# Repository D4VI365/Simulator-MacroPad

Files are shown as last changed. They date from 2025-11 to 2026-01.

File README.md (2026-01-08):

# Simulator-MacroPad

My project for the macropad contest of hackclub. It has 12 buttons as well as 1 rotary encoder with two leds which indicate the level of the encoder using colours.

I plan on using this pad to help me with my in-race adjustments, as well using it in other applications by mapping the buttons to do specific actions (like muting discord or actions of voicemod) or attaching more complex macros to them

BottomBox:

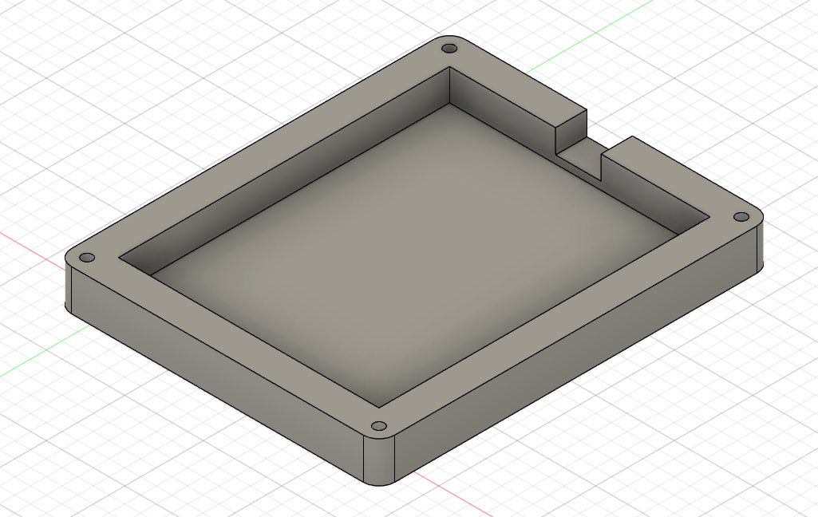
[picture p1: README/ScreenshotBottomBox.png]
BottomBox


TopCover:
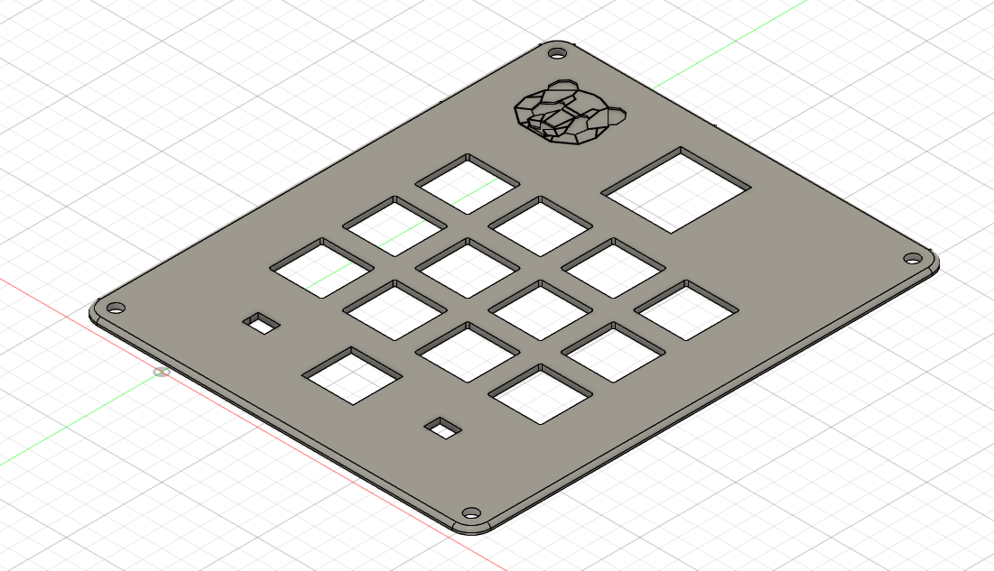
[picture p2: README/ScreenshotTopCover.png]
TopCover


FullBox:
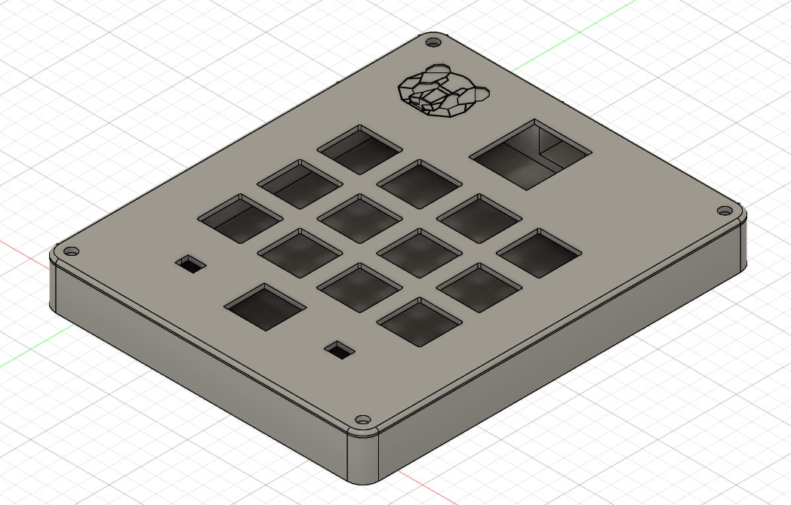
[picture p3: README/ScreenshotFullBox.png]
FullBox


BottomBox+PCB:
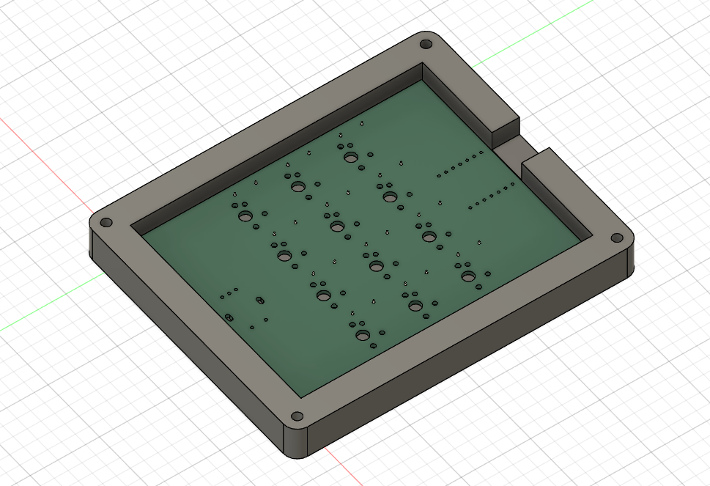
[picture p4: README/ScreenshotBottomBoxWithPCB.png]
BottomBoxWithPCB


Full Assemble:
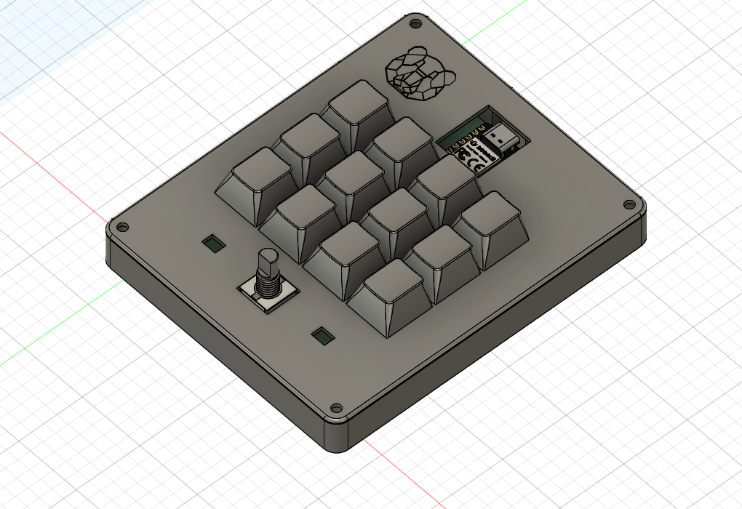
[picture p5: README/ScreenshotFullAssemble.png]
FullAssemble


PCB:
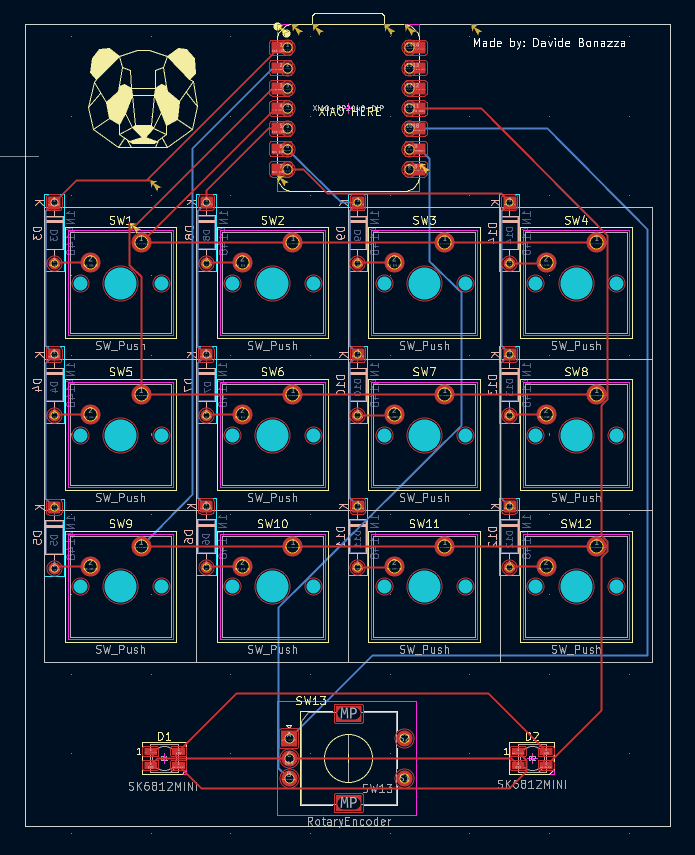
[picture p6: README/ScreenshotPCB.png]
PCB


Wiring Schematic:
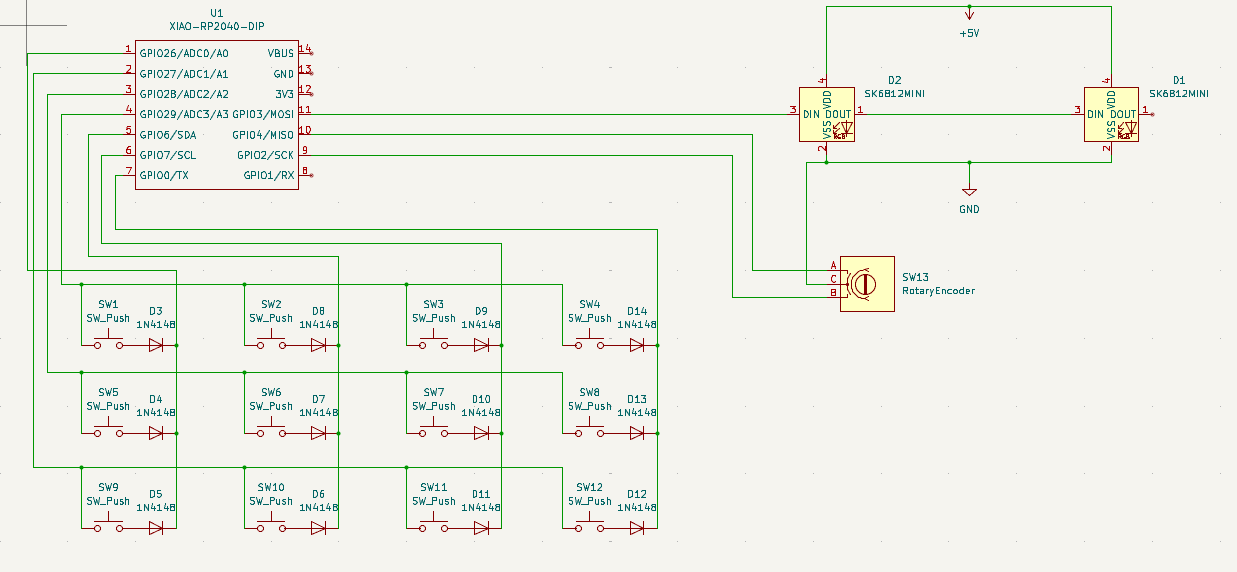
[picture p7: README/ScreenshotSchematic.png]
Schematic


Completed Design:
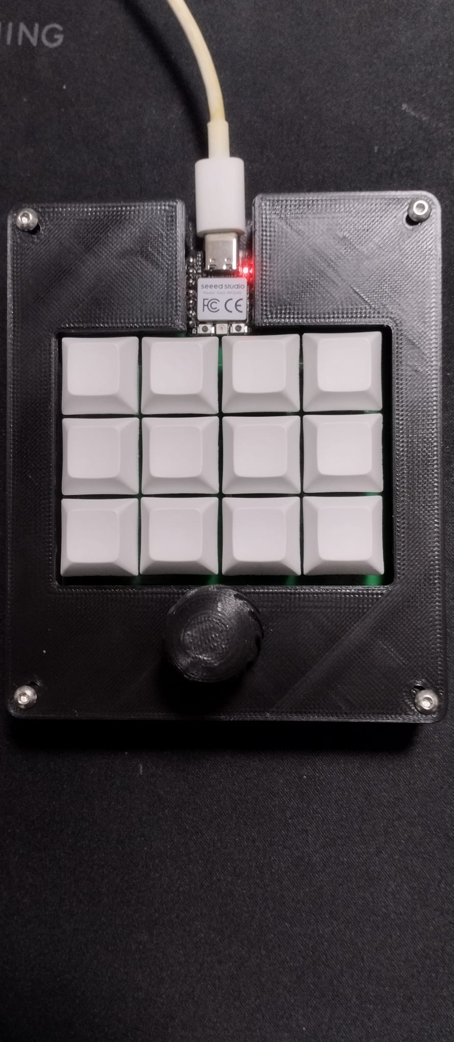
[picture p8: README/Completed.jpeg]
Completed


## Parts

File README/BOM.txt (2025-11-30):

List of materials needed for the project:

1x 	Seeed XIAO RP2040
12x 	Through-hole 1N4148 Diode
12x	MX-Style switche
1x	EC11 Rotary encoder
12x	Blank DSA keycap
2x	SK6812 MINI-E LED
4x	M3x16mm screw
4x	M3x5mx4mm heatset insert

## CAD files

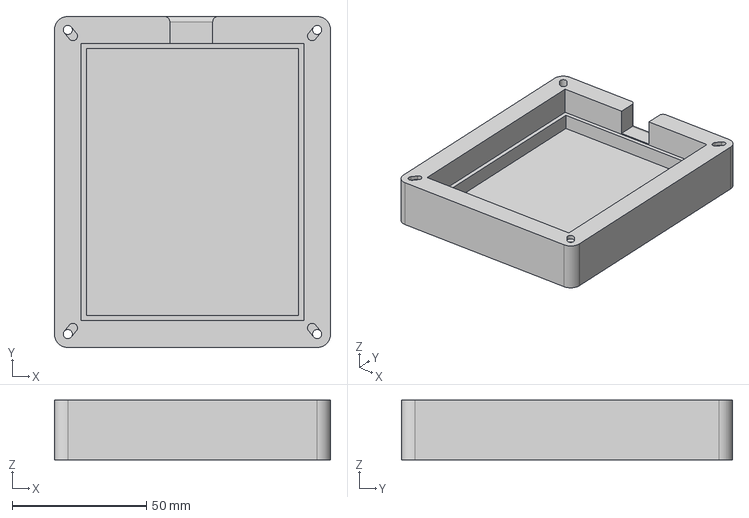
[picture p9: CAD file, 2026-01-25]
CAD/UpperFrame.step
103.0 x 123.4 x 22.3 mm

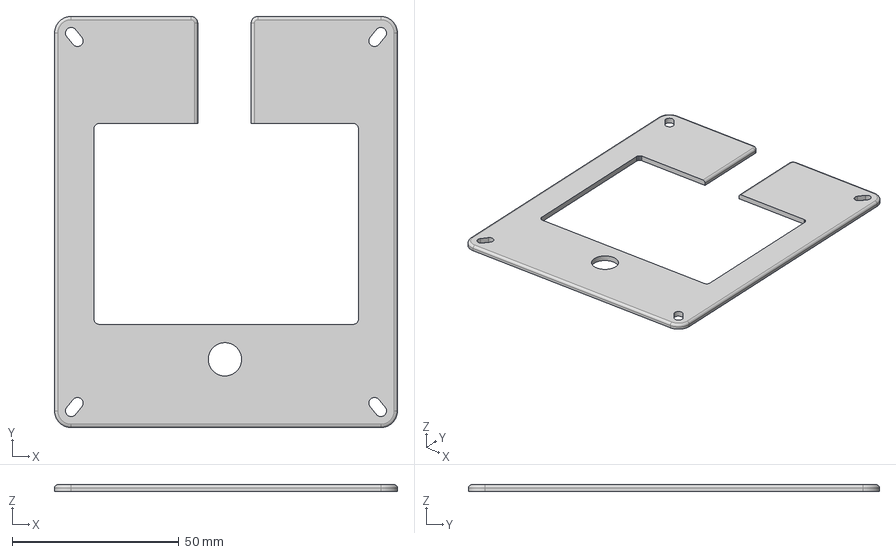
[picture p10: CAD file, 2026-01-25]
CAD/BottomBox.step
103.0 x 123.4 x 2.00 mm

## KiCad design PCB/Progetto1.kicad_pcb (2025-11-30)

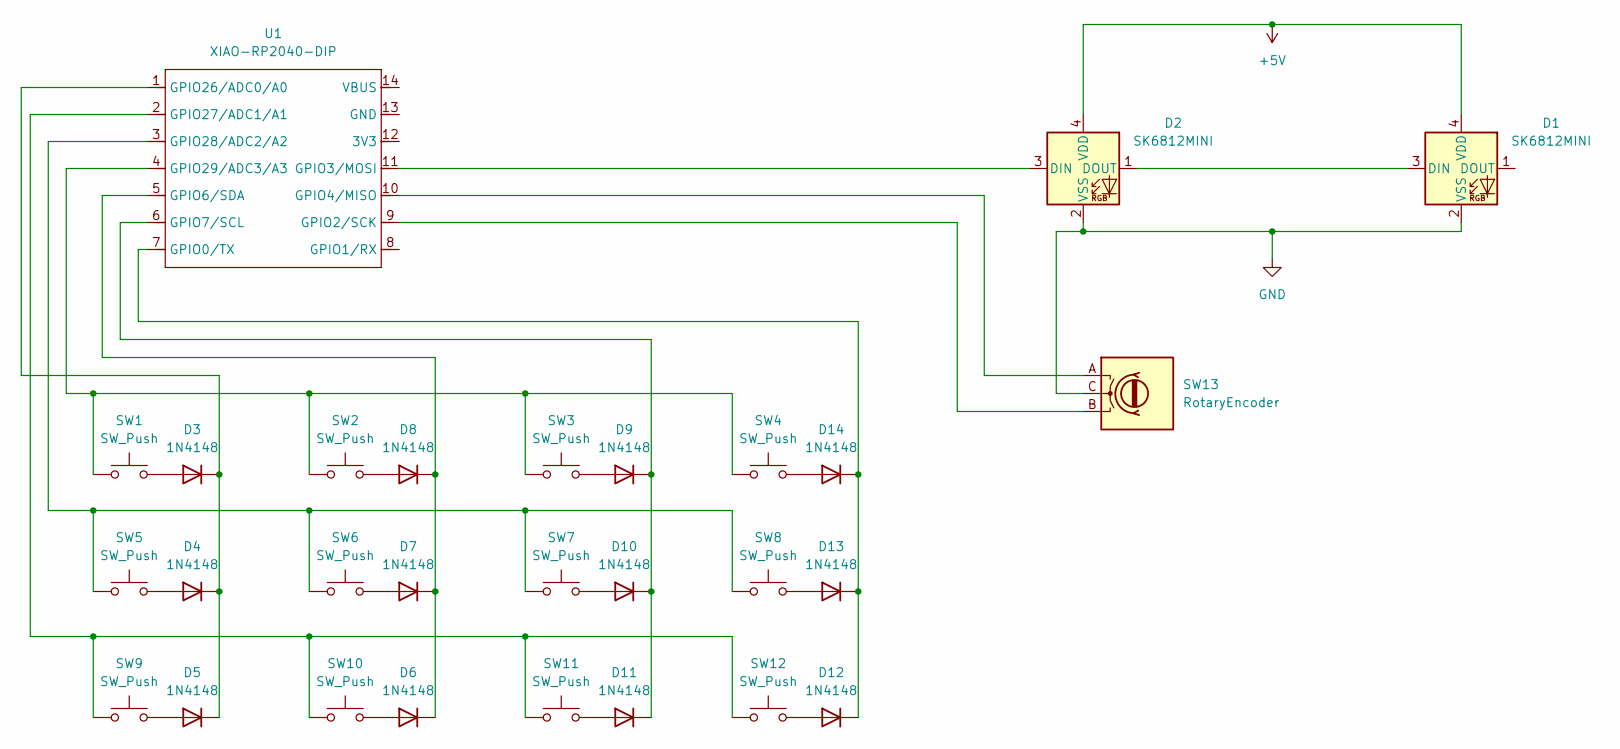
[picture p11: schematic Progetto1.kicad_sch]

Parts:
D1, D2: SK6812MINI; LED_SK6812MINI_PLCC4_3.5x3.5mm_P1.75mm
D3, D4, D5, D6, D7, D8, D9, D10, D11, D12, D13, D14: 1N4148; D_DO-35_SOD27_P7.62mm_Horizontal
SW1, SW2, SW3, SW4, SW5, SW6, SW7, SW8, SW9, SW10, SW11, SW12: SW_Push; SW_Cherry_MX_1.00u_PCB
SW13: RotaryEncoder; RotaryEncoder_Alps_EC11E-Switch_Vertical_H20mm
U1: XIAO-RP2040-DIP

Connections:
+5V: D1.4 (VDD), D2.4 (VDD)
GND: D1.2 (VSS), D2.2 (VSS), SW13.C
unnamed: D1.3 (DIN), D2.1 (DOUT)
unnamed: D2.3 (DIN), U1.11 (GPIO3/MOSI)
unnamed: D3.2 (A), SW1.2
unnamed: D3.1 (K), D4.1 (K), D5.1 (K), U1.1 (GPIO26/ADC0/A0)
unnamed: D4.2 (A), SW5.2
unnamed: D5.2 (A), SW9.2
unnamed: D6.2 (A), SW10.2
unnamed: D6.1 (K), D7.1 (K), D8.1 (K), U1.5 (GPIO6/SDA)
unnamed: D7.2 (A), SW6.2
unnamed: D8.2 (A), SW2.2
unnamed: D9.2 (A), SW3.2
unnamed: D10.2 (A), SW7.2
unnamed: D9.1 (K), D10.1 (K), D11.1 (K), U1.6 (GPIO7/SCL)
unnamed: D11.2 (A), SW11.2
unnamed: D12.2 (A), SW12.2
unnamed: D12.1 (K), D13.1 (K), D14.1 (K), U1.7 (GPIO0/TX)
unnamed: D13.2 (A), SW8.2
unnamed: D14.2 (A), SW4.2
unnamed: SW13.B, U1.9 (GPIO2/SCK)
unnamed: SW13.A, U1.10 (GPIO4/MISO)
unnamed: SW9.1, SW10.1, SW11.1, SW12.1, U1.2 (GPIO27/ADC1/A1)
unnamed: SW5.1, SW6.1, SW7.1, SW8.1, U1.3 (GPIO28/ADC2/A2)
unnamed: SW1.1, SW2.1, SW3.1, SW4.1, U1.4 (GPIO29/ADC3/A3)

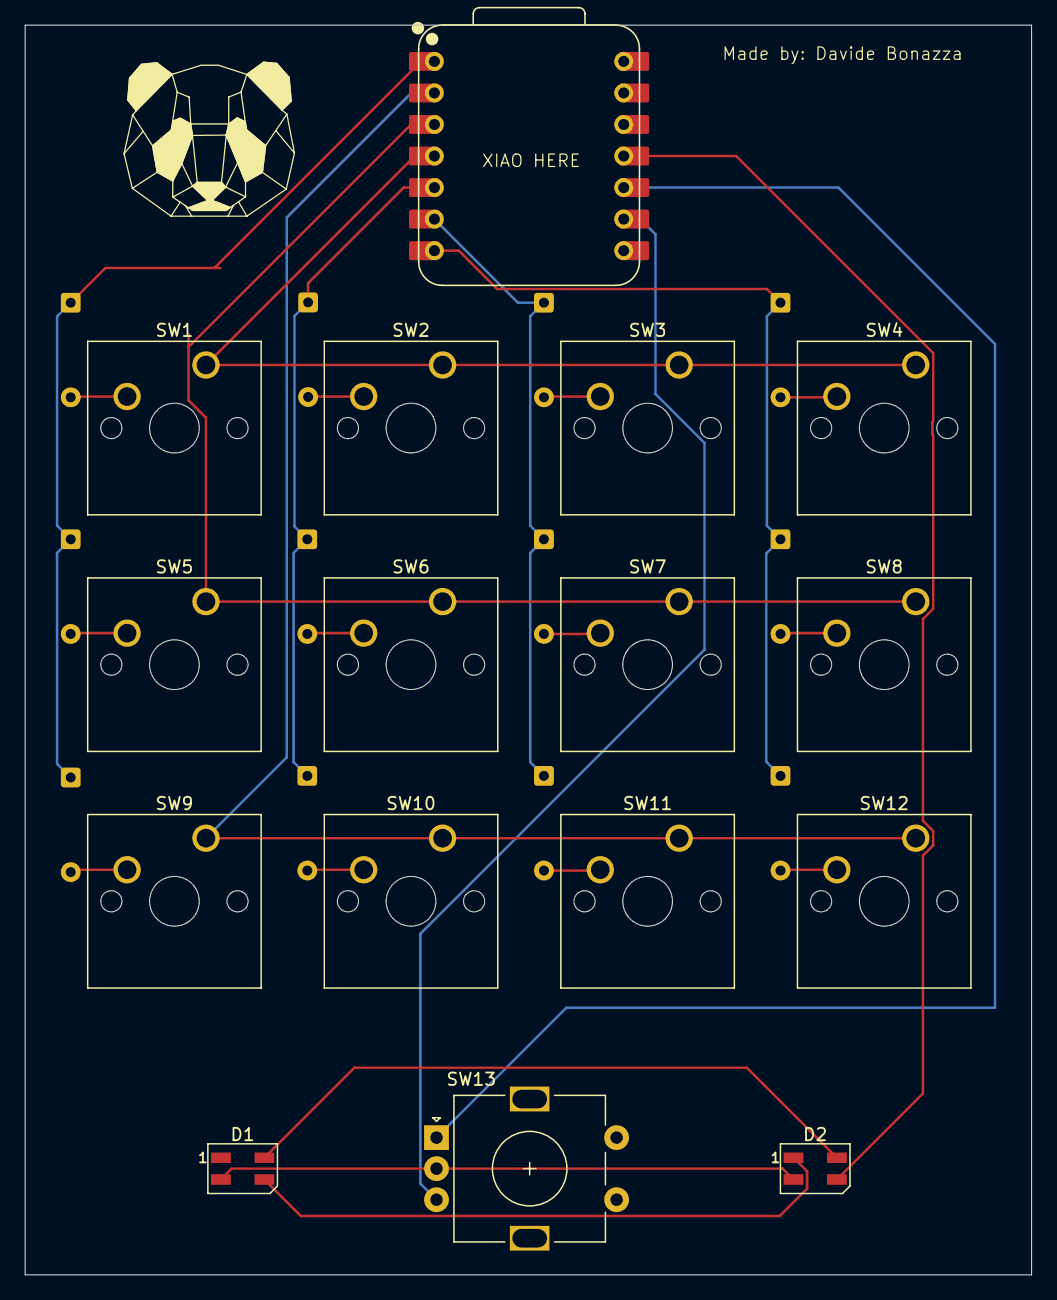
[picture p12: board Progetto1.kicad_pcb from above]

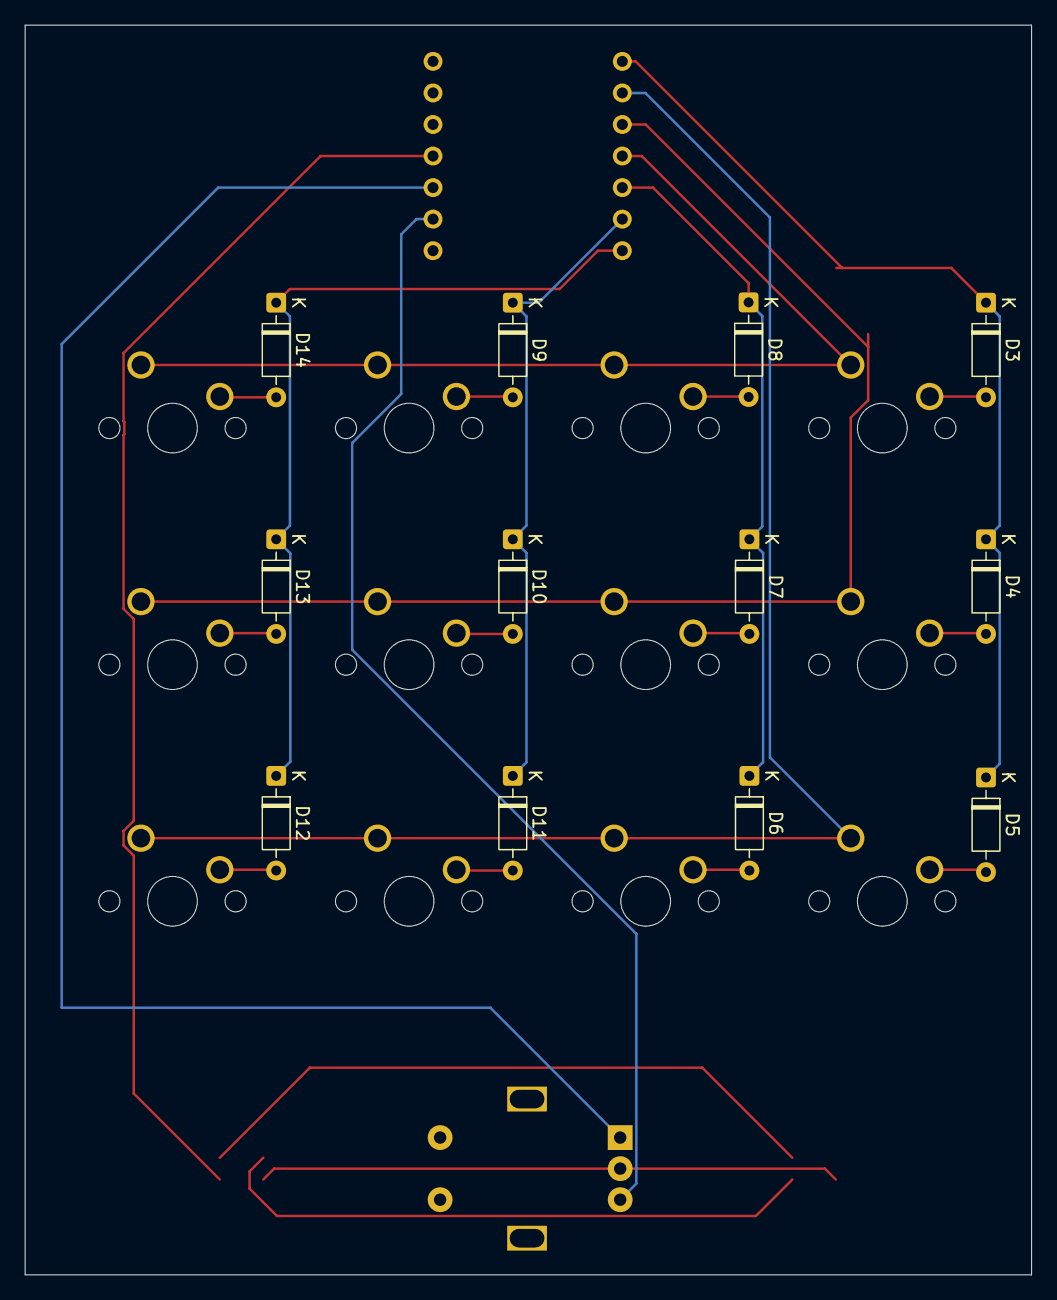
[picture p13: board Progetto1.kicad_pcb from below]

Board: 2 copper layers, 81.0 x 100.6 mm, 28 parts (12 on the bottom side), 25 nets.

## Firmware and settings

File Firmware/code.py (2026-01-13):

import digitalio
import board
import time
import usb_hid
import neopixel
import rotaryio
from adafruit_hid.keyboard import Keyboard
from adafruit_hid.keycode import Keycode

#Funzione controllo della matrice tasti
def CheckMatrix():
    for maggio in range(len(ROW)):
        ROW[maggio].value=True
        led.fill((0,0,0))
        for tello in range(len(COL)):
            led.fill((0,0,0))
            if COL[tello].value==True:
                led.fill((0,255,0))
                kbd.send(MAP[maggio][tello])
                while COL[tello].value==True:
                    time.sleep(0.001)

        ROW[maggio].value=False

led = neopixel.NeoPixel(board.NEOPIXEL, 1)
led.brightness=0.3
led.fill((0,0,0))

#Led configurato sui pin D2 e D1
encoder = rotaryio.IncrementalEncoder(board.D2, board.D1)

last_position = 0

#Dichiarazione righe
ROW = [
    board.D3, board.D9, board.D7
]

for chetta in range(len(ROW)):
    ROW[chetta]=digitalio.DigitalInOut(ROW[chetta])
    ROW[chetta].direction = digitalio.Direction.OUTPUT

#Dichiarazione colonne
COL =[
    board.D0, board.D4, board.D5, board.D6
]

for tello in range(len(COL)):
    COL[tello] = digitalio.DigitalInOut(COL[tello])
    COL[tello].switch_to_input(pull=digitalio.Pull.DOWN)


#KEYMAP
kbd = Keyboard(usb_hid.devices)

MAP = [[Keycode.F13, Keycode.F14, Keycode.F15, Keycode.F16],
       [Keycode.F17, Keycode.F18, Keycode.F19, Keycode.F20],
       [Keycode.F21, Keycode.F22, Keycode.F23, Keycode.F24]]

while True:
    led.fill((0,0,0))
    CheckMatrix()
    current_position = encoder.position

    if current_position != last_position:
        if current_position > last_position:
            # Rotazione Oraria -> Blu
            kbd.send(Keycode.SHIFT, Keycode.F1)
            led.fill((0, 0, 255))
            print("Rotazione Oraria (+)")
        else:
            # Rotazione Antioraria -> Giallo
            kbd.send(Keycode.CONTROL, Keycode.F1)
            led.fill((255, 255, 0))
            print("Rotazione Antioraria (-)")

        last_position = current_position

        # Aspetta un attimo e spegni il LED per evidenziare lo scatto
        time.sleep(0.05)
        led.fill((0, 0, 0))

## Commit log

2025-11-30 add README
    [BottomBox.step, FullBox.step, Progetto1.kicad_pcb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]
2026-01-13 Refactor encoder handling and remove test script
    Deleted the obsolete 'Test led/code.py' test script. Moved encoder handling logic directly into the main loop in 'code.py', replacing the separate CheckEncoder function. Now, encoder rotation trigger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
2026-01-25 Update CAD files: add BottomBox and UpperFrame, remove frames
    Added BottomBox.step and UpperFrame.step to the CAD directory. Removed obsolete BottomFrame.stl and TopFrame.stl files. This updates the CAD models to the latest STEP format and removes outdated STL 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
    [BottomBox.step, BottomFrame.stl, TopFrame.stl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]
